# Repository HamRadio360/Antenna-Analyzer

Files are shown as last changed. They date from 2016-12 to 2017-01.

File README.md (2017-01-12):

Ham Radio 360 Logo Workbench Podcast Logo Workbench Logo

# K6BEZ Antenna Analyzer

The K6BEZ antenna analyzer will provide VSWR measurements for any antenna from 1 to 30 MHz.  Frequency and VSWR is shown on the built in LCD display.  Data can optionally be sent over the USB cable to a PC running a program that will plot the VSWR on a graphical window display.
The analyzer can be programmed to scan any sub band and has built in ranges for 160m, 80m, 60m, 40m, 30m, 20m, 17m, 15m, 12m, 10m. 

For more information check out the [project website](http://www.360workbench.com/) and the [Ham Radio 360 forum](http://hamradio360.com/community/main-forum/).

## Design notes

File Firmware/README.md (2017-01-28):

Ham Radio 360 Logo Workbench Podcast Logo Workbench Logo

# Firmware

This directory contains the firmware for the K6BEZ Antenna Analyzer.

Currently the firmware supports revision 6 and 7 PCBs with Arduino Pro Mini compatible microcontrollers and Analog Devices AD9850 synthesizers.

## Standard Firmware

This is the firmware originally developed by K6BEZ and supports the core features of the antenna analyzer. If you are getting started or want reliable and stable software use the standard firmware.

## Advanced Firmware

This firmware contains more features but may require more work to build and install.

# Issues, Bugs, Ideas for improvements

We are tracking all issues and ideas for improvements using the [GitHub issues](https://github.com/HamRadio360/Antenna-Analyzer/issues) tracker.

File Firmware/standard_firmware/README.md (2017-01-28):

Ham Radio 360 Logo Workbench Podcast Logo Workbench Logo

# Standard Firmware

This directory contains the standard firmware for the K6BEZ Antenna Analyzer.

Currently the firmware supports revision 6 and 7 PCBs with Arduino Pro Mini compatible microcontrollers and Analog Devices AD9850 synthesizers.

# Installing

The firmware can be built and installed using the Arduino Integrated Development Environment (IDE).

1. Install the [Arduino IDE Editor & Compiler](https://www.arduino.cc/en/Main/Software)
2. Add the SparkFun Board Manager URLs
  * Go to File / Preferences, and paste this URL into the 'Additional Boards Manager URLs' input field...
  * https://raw.githubusercontent.com/sparkfun/Arduino_Boards/master/IDE_Board_Manager/package_sparkfun_index.json
3. Install the Arduino Pro Micro board definitions file
  * This board file will work for the SparkFun or DealExtreme Arduino Pro Micro board
  * In the Arduino IDE, click Tools / Board / then scroll to the top and click <Board Manager>
  * At the top of the Board Manager enter "sparkfun" and hit return
  * You will see multiple Sparkfun board definition sets
  * Click on the box labeled “SparkFun AVR Boards”
  * Click **Install**
4. Open the firmware project
  * Go to File / Open and select the `aa_firmware.ino` file
5. Select the target board
  * Go to Tools / Board and scroll down to select "SparkFun Pro Micro"
  * Go to Tools / Processor and select "ATmega32u4 (5V, 16 MHz)"
  * Go to Tools / Port and select the correct Serial Port. This varies based on your Operating System and computer hardware.
5. Upload the firmware
  * Go to Sketch / Upload

# Troubleshooting

The Arduino IDE and the USB connection can be inconsistent sometimes. There are many resources online talking about programming the Arduino on every imaginable operating system and with almost any error.

If you have problems the [Ham Radio 360 Forum](http://hamradio360.com/community/build-discussion/) is a good place to ask. Please include what operating system you are on and any error message you've encountered.

# Issues, Bugs, Ideas for improvements

We are tracking all issues and ideas for improvements using the [GitHub issues](https://github.com/HamRadio360/Antenna-Analyzer/issues) tracker.

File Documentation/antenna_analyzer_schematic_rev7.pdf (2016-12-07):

# Antenna Analyzer Rev 7 Schematic

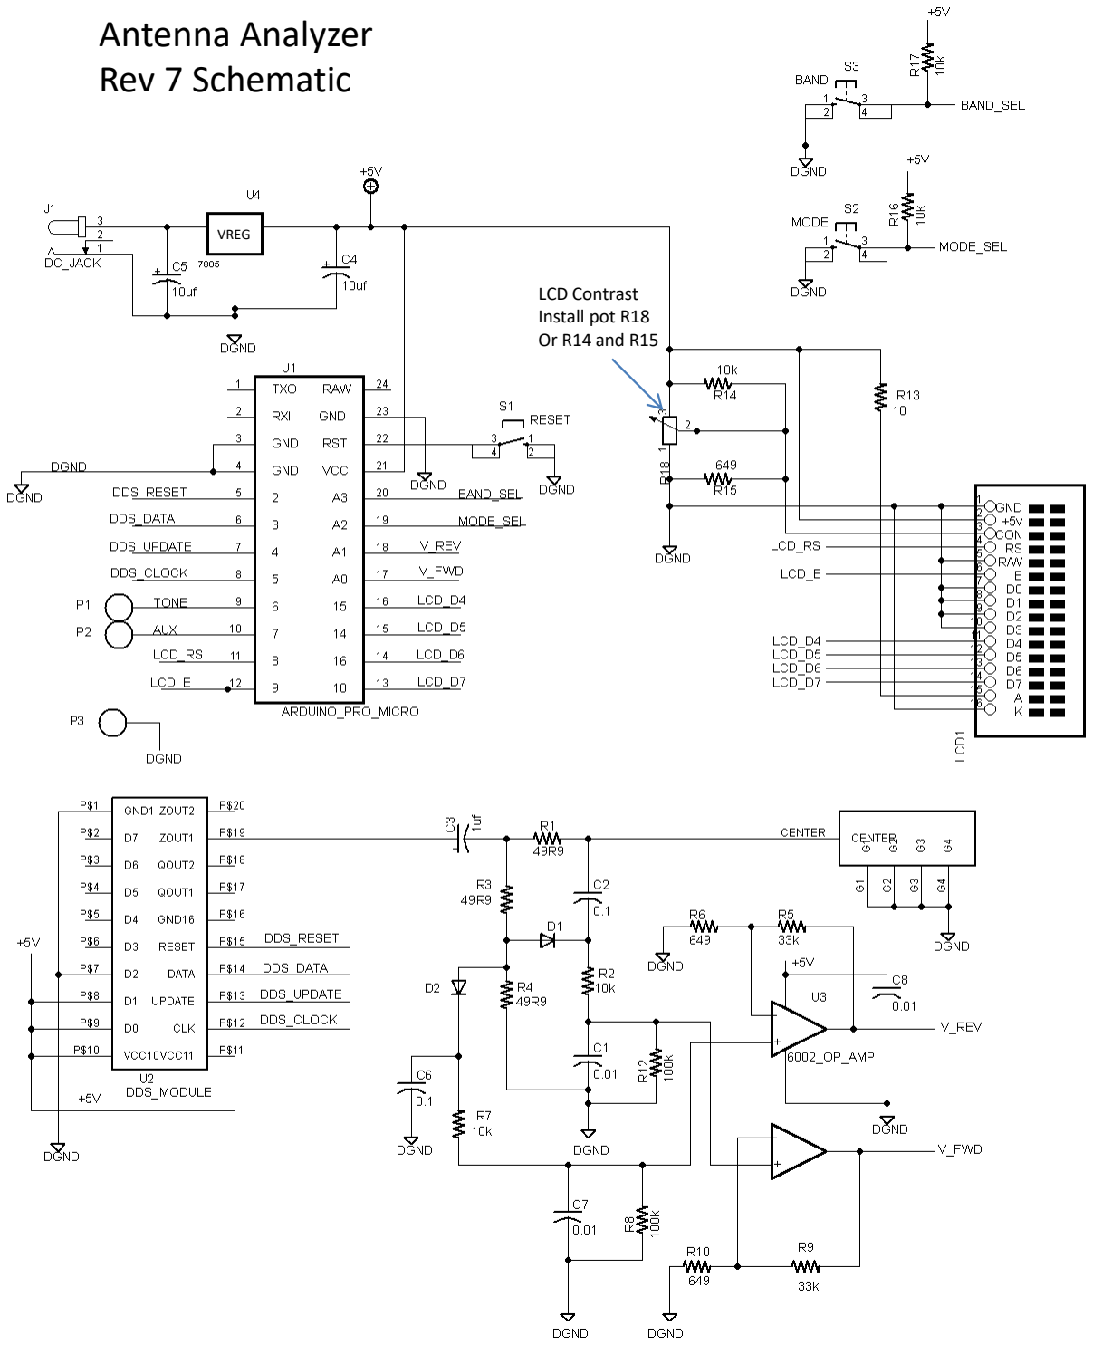
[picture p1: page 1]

VREG

LCD Contrast
Install pot R18
Or R14 and R15

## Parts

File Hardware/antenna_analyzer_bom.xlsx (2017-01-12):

HamRadio 360 Workbench - K6BEZ Antenna Analyzer Bill of Materials
Type | Part | Description | Value | Digikey Part # | Est Price | Web Site
Connector | CON1 | Right angle BNC connector |  | A97569-ND | $3.88
Connector | J1 | DC power jack 2.1mm |  | CP-102AH-ND | $1.18
Capacitor | C1 | 0.1" spaced dipped mono 10% | 0.01 | 399-4260-ND | $0.24
Capacitor | C2 | 0.1" spaced dipped mono 10% | 0.1 | BC1084CT-ND | $0.22
Capacitor | C3 | Electrolytic capacitor 25v | 1uf | 493-10461-1-ND | $0.10
Capacitor | C4 | Electrolytic capacitor 25v | 10uf | P980-ND | $0.23
Capacitor | C5 | Electrolytic capacitor 25v | 10uf | P980-ND | $0.23
Capacitor | C6 | 0.1" spaced dipped mono 10% | 0.1 | BC1084CT-ND | $0.22
Capacitor | C7 | 0.1" spaced dipped mono 10% | 0.01 | 399-4260-ND | $0.24
Capacitor | C8 | 0.1" spaced dipped mono 10% | 0.01 | 399-4260-ND | $0.24
Resistor | R1 | 1/4 Watt 5% | 49.9 | 49.9XBK-ND | $0.10
Resistor | R2 | 1/4 Watt 5% | 10k | 10KQBK-ND | $0.10
Resistor | R3 | 1/4 Watt 5% | 49.9 | 49.9XBK-ND | $0.10
Resistor | R4 | 1/4 Watt 5% | 49.9 | 49.9XBK-ND | $0.10
Resistor | R5 | 1/4 Watt 5% | 649 | 649XBK-ND | $0.10
Resistor | R6 | 1/4 Watt 5% | 33k | 33KQBK-ND | $0.10
Resistor | R7 | 1/4 Watt 5% | 10k | 10KQBK-ND | $0.10
Resistor | R8 | 1/4 Watt 5% | 100k | 100KQBK-ND | $0.10
Resistor | R9 | 1/4 Watt 5% | 649 | 649XBK-ND | $0.10
Resistor | R10 | 1/4 Watt 5% | 33k | 33KQBK-ND | $0.10
Resistor | R12 | 1/4 Watt 5% | 100k | 100KQBK-ND | $0.10
Resistor | R13 | 1/4 Watt 5% | 10 | 10QBK-ND | $0.10
Resistor | R14 | 1/4 Watt 5% | 10k | 10KQBK-ND | $0.10
Resistor | R15 | 1/4 Watt 5% | 649 | 649XBK-ND | $0.10
Resistor | R16 | 1/4 Watt 5% | 10k | 10KQBK-ND | $0.10
Resistor | R17 | 1/4 Watt 5% | 10k | 10KQBK-ND | $0.10
Switch | S1 | Tactile pushbutton switch |  | 450-1650-ND | $0.10
Switch | S2 | Tactile pushbutton switch |  | 450-1650-ND | $0.10
Switch | S3 | Tactile pushbutton switch |  | 450-1650-ND | $0.10
Integrated Circuit | U3 | MCP 6002 Dual OpAmp |  | MCP6002-E/P-ND | $0.36
Integrated Circuit | U4 | 5v DC / DC converter OKI-78SR-5/1.5-W36H-C |  | 811-2692-ND | $4.31
Mechanical | X1 | 10 pin female header |  | S7043-ND | $0.85
Mechanical | X2 | 10 pin female header |  | S7043-ND | $0.85
Mechanical | X3 | 16 pin male header 0.1" pitch |  | S1011EC-16-ND | $0.40
Mechanical | X4 | 4-40 Hex standoff 1/4" long, 3/16" diameter |  | 36-1891-ND | $0.40
Mechanical | X5 | 4-40 Hex standoff 1/4" long, 3/16" diameter |  | 36-1891-ND | $0.40
Mechanical | X6 | 4-40 Hex standoff 1/4" long, 3/16" diameter |  | 36-1891-ND | $0.40
Mechanical | X7 | 4-40 Hex standoff 1/4" long, 3/16" diameter |  | 36-1891-ND | $0.40
Mechanical | X8 | 4-40 Hex standoff 1/4" long, 3/16" diameter |  | 36-1891-ND | $0.40
Mechanical | X9 | 4-40 Hex standoff 1/4" long, 3/16" diameter |  | 36-1891-ND | $0.40
Mechanical | X10 | 4-40 Hex standoff 1/4" long, 3/16" diameter |  | 36-1891-ND | $0.40
Mechanical | X11 | 4-40 Hex standoff 1/4" long, 3/16" diameter |  | 36-1891-ND | $0.40
Mechanical | X12 | 4-40 1/4" pan head philips screw |  | 36-9900-ND | $0.10
Mechanical | X13 | 4-40 1/4" pan head philips screw |  | 36-9900-ND | $0.10
Mechanical | X14 | 4-40 1/4" pan head philips screw |  | 36-9900-ND | $0.10
Mechanical | X15 | 4-40 1/4" pan head philips screw |  | 36-9900-ND | $0.10
Mechanical | X16 | 4-40 hex nut |  | 36-4694-ND | $0.08
Mechanical | X17 | 4-40 hex nut |  | 36-4694-ND | $0.08
Mechanical | X18 | 4-40 hex nut |  | 36-4694-ND | $0.08
Mechanical | X19 | 4-40 hex nut |  | 36-4694-ND | $0.08
Mechanical | X20 | 4-40 1/2" pan head philips screw |  | 36-9902-ND | $0.12
Mechanical | X21 | 4-40 1/2" pan head philips screw |  | 36-9902-ND | $0.12
Mechanical | X22 | 4-40 1/2" pan head philips screw |  | 36-9902-ND | $0.12
Mechanical | X23 | 4-40 1/2" pan head philips screw |  | 36-9902-ND | $0.12
Mechanical | X24 | 8 pin DIP socket |  | AE9986-ND | $0.18
 |  |  |  |  | $20.03
Components from Other Internet Sources
Item | Part | Description | Price | Web Site
Integrated Circuit | U1 | Arduino Pro Micro | 5.71 | http://www.dx.com/p/pro-micro-atmega-32u4-5v-16mhz-development-board-module-for-arduino-deep-blue-320958
Integrated Circuit | U2 | AD9850 DDS Module | 12.1 | http://www.ebay.com/itm/AD9850-DDS-Signal-Generator-Module-0-40MHz-2-Sine-Wave-And-2-Square-Wave-Output-/170910337597
LCD | LCD1 | 2x16 LCD Display | $3.41 | http://www.ebay.com/itm/1602-162-16x2-Character-LCD-Display-Module-HD44780-Controller-Yellow-Blacklight-/400436751565
Components from PackTenna
Item | Part | Description | Price | Web Site
Antenna Analyzer Parts Kit includes… |  |  | $16.80
 | PCB | Printed circuit board
 | D1 | AA143 Germanium diode
 | D2 | AA143 Germanium diode

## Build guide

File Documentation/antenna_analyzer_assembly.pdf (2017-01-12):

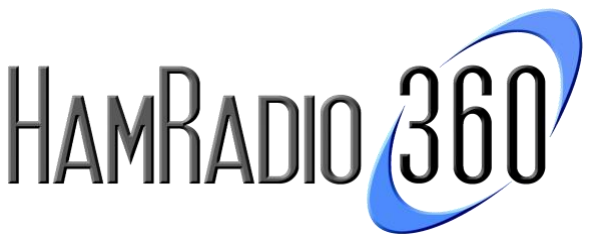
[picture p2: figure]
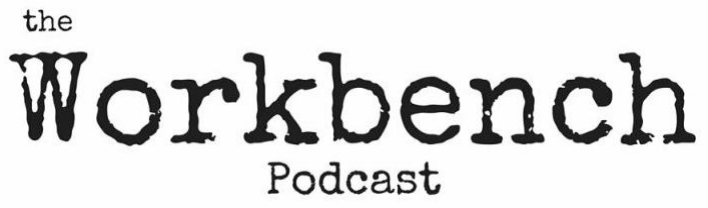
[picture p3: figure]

# Antenna Analyzer Assembly Guide

## Rev 1.1

## Introduction

The Workbench antenna analyzer project was designed by Beric Dunn, K6BEZ. This assembly guide explains how to build the antenna analyzer. The theory of operation is documented elsewhere. For all the latest documents go to www.360workbench.com

## General Assembly Instructions

We recommend assembling the antenna analyzer in the following order.

Install all low profile components first.
☐ Install all resistors
If you have a version 6 board read the page “Alert ! Rev 6 Board Changes“ page in this document to see the four silkscreen changes to the board.
If you have a version 7 or later board, install the resistors as marked on the board.
☐ Install all capacitors
☐ Install the two glass germanium diodes
☐ Install the 8 pin IC socket
☐ Install the 3 tactile switches
Install connectors
☐ Install the two 10 pin female header sockets for the DDS module
☐ Install the one 16 pin male header connector for the LCD display
☐ Install the two 12 pin male header connectors for the Arduino module ☐ Install the DC coaxial power jack
☐ Install the BNC coax jack
Install the voltage regulator
☐ Install the voltage regulator module.
At this point, check to make sure the DC voltages are correct. See the DC Test Point page. Install standoffs
☐ Install the 4 ¼” hex standoffs to the LCD module using 4 of the ½” 4-40 screws
☐ Install the 4 ¼” hex standoffs to the main PCB in the corners using 4-40 screws
Mount the LCD
☐ Place the ½” screws that are part of the LCD module through the holes on the PCB and attach with 4-40 nuts on the bottom of the board
Install Arduino
☐ Place the Arduino module on the male headers and solder. Make sure the micro USB jack is pointing to the edge of the board.
Install the DDS module
☐ Plug the DDS module on to the main PCB.

## Antenna Analyzer Rev 7 Schematic

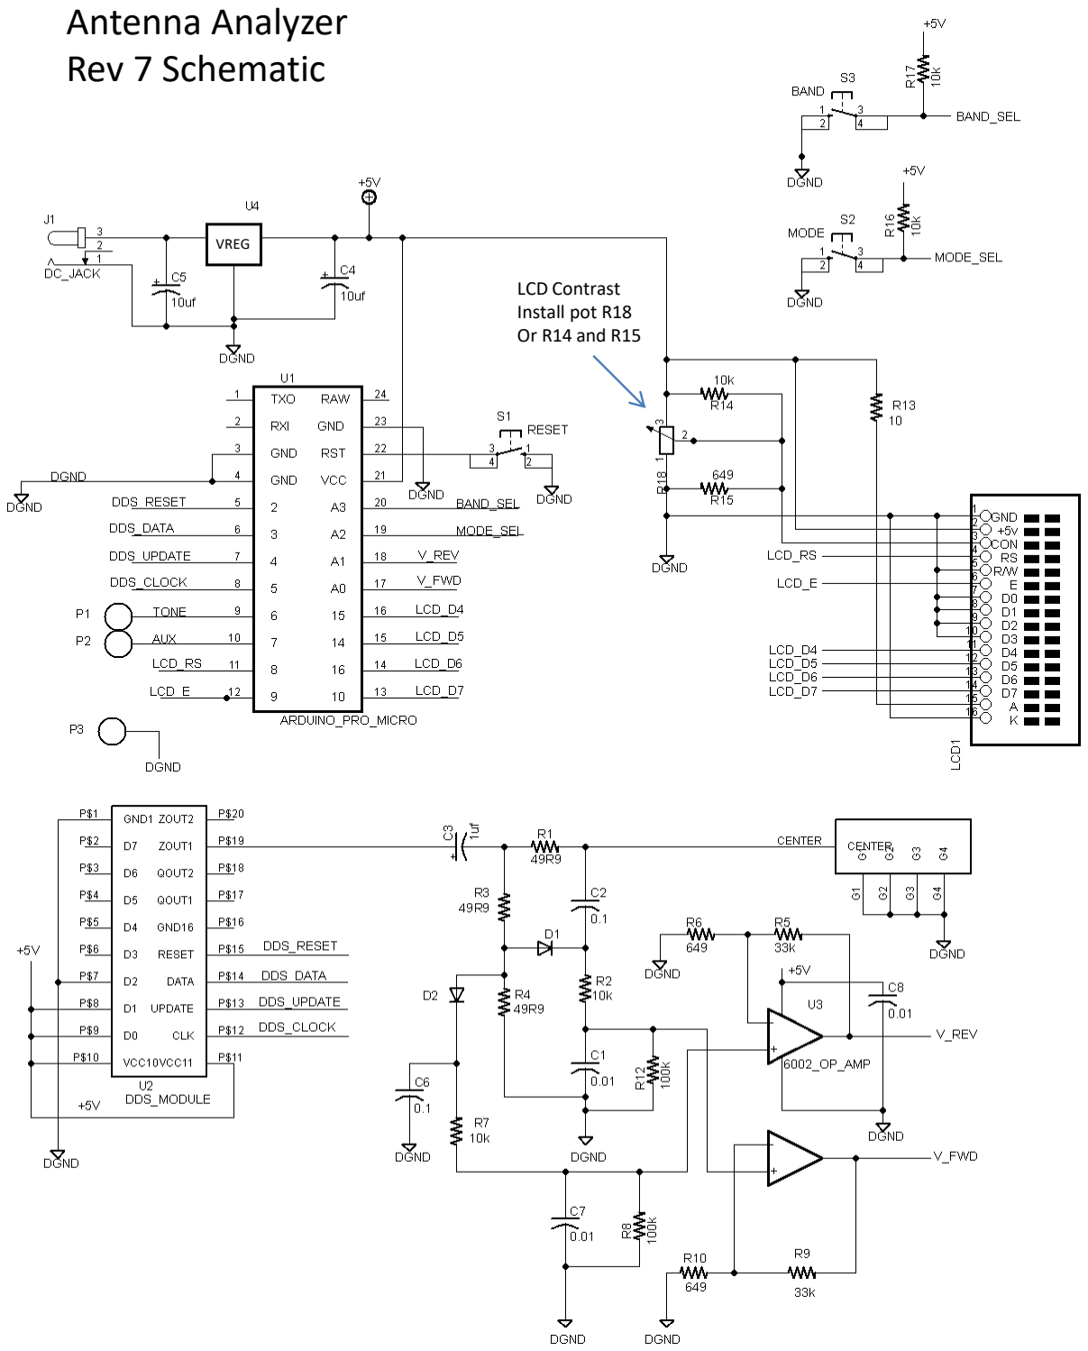
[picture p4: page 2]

VREG

LCD Contrast
Install pot R18
Or R14 and R15

# Bill of Materials

Type | Part | Description | Value | Digikey Part #
Connector | CON1 | Right angle BNC connector | A97569-ND
Connector | J1 | DC power jack 2.1mm | CP-102AH-ND
Capacitor | C1 | 0.1" spaced dipped mono 10% | 0.01 | 399-4260-ND
Capacitor | C2 | 0.1" spaced dipped mono 10% | 0.1 | BC1084CT-ND
Capacitor | C3 | Electrolytic capacitor 25v | 1uf | 493-10461-1-ND
Capacitor | C4 | Electrolytic capacitor 25v | 10uf | P980-ND
Capacitor | C5 | Electrolytic capacitor 25v | 10uf | P980-ND
Capacitor | C6 | 0.1" spaced dipped mono 10% | 0.1 | BC1084CT-ND
Capacitor | C7 | 0.1" spaced dipped mono 10% | 0.01 | 399-4260-ND
Capacitor | C8 | 0.1" spaced dipped mono 10% | 0.01 | 399-4260-ND
Resistor | R1 | 1/4 Watt 5% | 49.9 | 49.9XBK-ND
Resistor | R2 | 1/4 Watt 5% | 10k | 10KQBK-ND
Resistor | R3 | 1/4 Watt 5% | 49.9 | 49.9XBK-ND
Resistor | R4 | 1/4 Watt 5% | 49.9 | 49.9XBK-ND
Resistor | R5 | 1/4 Watt 5% | 649 | 649XBK-ND
Resistor | R6 | 1/4 Watt 5% | 33k | 33KQBK-ND
Resistor | R7 | 1/4 Watt 5% | 10k | 10KQBK-ND
Resistor | R8 | 1/4 Watt 5% | 100k | 100KQBK-ND
Resistor | R9 | 1/4 Watt 5% | 649 | 649XBK-ND
Resistor | R10 | 1/4 Watt 5% | 33k | 33KQBK-ND
Resistor | R12 | 1/4 Watt 5% | 100k | 100KQBK-ND
Resistor | R13 | 1/4 Watt 5% | 10 | 10QBK-ND
Resistor | R14 | 1/4 Watt 5% | 10k | 10KQBK-ND
Resistor | R15 | 1/4 Watt 5% | 649 | 649XBK-ND
Resistor | R16 | 1/4 Watt 5% | 10k | 10KQBK-ND
Resistor | R17 | 1/4 Watt 5% | 10k | 10KQBK-ND
Switch | S1 | Tactile pushbutton switch | 450-1650-ND
Switch | S2 | Tactile pushbutton switch | 450-1650-ND
Switch | S3 | Tactile pushbutton switch | 450-1650-ND
Integrated Circuit | U3 | MCP 6002 Dual OpAmp | MCP6002-E/P-ND
Integrated Circuit | U4 | 5v DC / DC converter OKI-78SR-5/1.5-W36H-C | 811-2692-ND

# Bill of Materials

Mechanical | X1 | 10 pin female header | S7043-ND
Mechanical | X2 | 10 pin female header | S7043-ND
Mechanical | X3 | 16 pin male header 0.1" pitch | S1011EC-16-ND
Mechanical | X4 | 4-40 Hex standoff 1/4" long, 3/16" diameter | 36-1891-ND
Mechanical | X5 | 4-40 Hex standoff 1/4" long, 3/16" diameter | 36-1891-ND
Mechanical | X6 | 4-40 Hex standoff 1/4" long, 3/16" diameter | 36-1891-ND
Mechanical | X7 | 4-40 Hex standoff 1/4" long, 3/16" diameter | 36-1891-ND
Mechanical | X8 | 4-40 Hex standoff 1/4" long, 3/16" diameter | 36-1891-ND
Mechanical | X9 | 4-40 Hex standoff 1/4" long, 3/16" diameter | 36-1891-ND
Mechanical | X10 | 4-40 Hex standoff 1/4" long, 3/16" diameter | 36-1891-ND
Mechanical | X11 | 4-40 Hex standoff 1/4" long, 3/16" diameter | 36-1891-ND
Mechanical | X12 | 4-40 1/4" pan head philips screw | 36-9900-ND
Mechanical | X13 | 4-40 1/4" pan head philips screw | 36-9900-ND
Mechanical | X14 | 4-40 1/4" pan head philips screw | 36-9900-ND
Mechanical | X15 | 4-40 1/4" pan head philips screw | 36-9900-ND
Mechanical | X16 | 4-40 hex nut | 36-4694-ND
Mechanical | X17 | 4-40 hex nut | 36-4694-ND
Mechanical | X18 | 4-40 hex nut | 36-4694-ND
Mechanical | X19 | 4-40 hex nut | 36-4694-ND
Mechanical | X20 | 4-40 1/2" pan head philips screw | 36-9902-ND
Mechanical | X21 | 4-40 1/2" pan head philips screw | 36-9902-ND
Mechanical | X22 | 4-40 1/2" pan head philips screw | 36-9902-ND
Mechanical | X23 | 4-40 1/2" pan head philips screw | 36-9902-ND
Mechanical | X24 | 8 pin DIP socket | AE9986-ND

Components from Other Internet Sources
Item | Part | Description
Integrated Circuit | U1 | Arduino Pro Micro
Integrated Circuit | U2 | AD9850 DDS Module
LCD | LCD1 | 2x16 LCD Display

Components from PackTenna
Item | Part | Description

Antenna Analyzer Parts Kit includes…
PCB | Printed circuit board
D1 | AA143 Germanium diode
D2 | AA143 Germanium diode

Arduino Pro Micro 5v Example http://www.dx.com/p/pro-micro-atmega-32u4-5v-16mhz-development-boardmodule-for-arduino-deep-blue-320958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
DDS Module example on Ebay http://www.ebay.com/itm/AD9850-DDS-Signal-Generator-Module-0-40MHz-2-Sine-Wave-And-2-Square-Wave-Output-/170910337597

LCD example on Ebay
http://www.ebay.com/itm/1602-162-16x2-Character-LCD-Display-Module-HD44780-Controller-Yellow-Blacklight-/400436751565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 iMAAOSwZVlXkHXi

## The Workbench – Antenna Analyzer Parts Placement Diagram

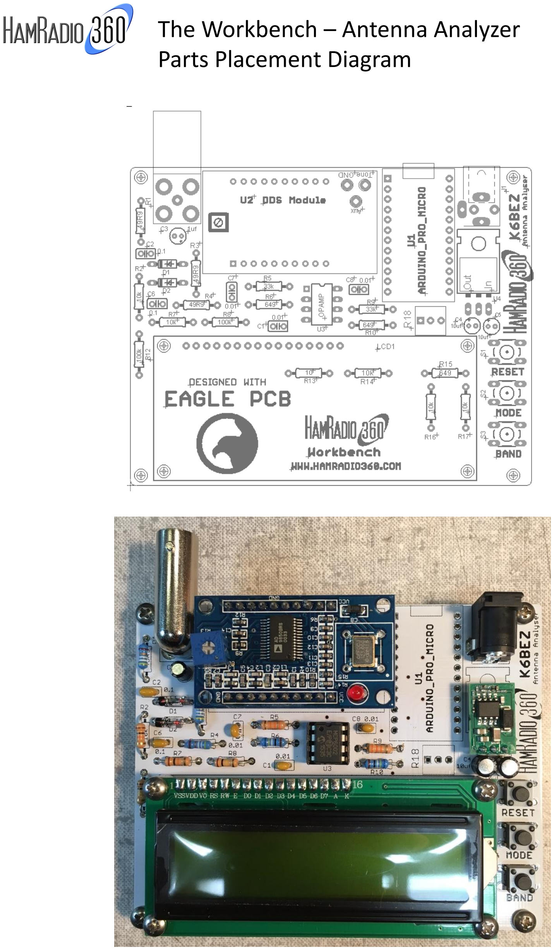
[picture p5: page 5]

Install all low profile components first.
☐ Install all resistors
☐ Install all capacitors
☐ Install the two glass germanium diodes ☐ Install the 8 pin IC socket
☐ Install the 3 tactile switches

Install connectors
☐ Install the two 10 pin female header sockets for the DDS module
☐ Install the one 16 pin male header connector for the LCD display
☐ Install the two 12 pin male header connectors for the Arduino module ☐ Install the DC coaxial power jack
☐ Install the BNC coax jack

Install the voltage regulator
☐ Install the voltage regulator module.

If you have a rev 6 board,

## look at the builder’s alert on

the next page.

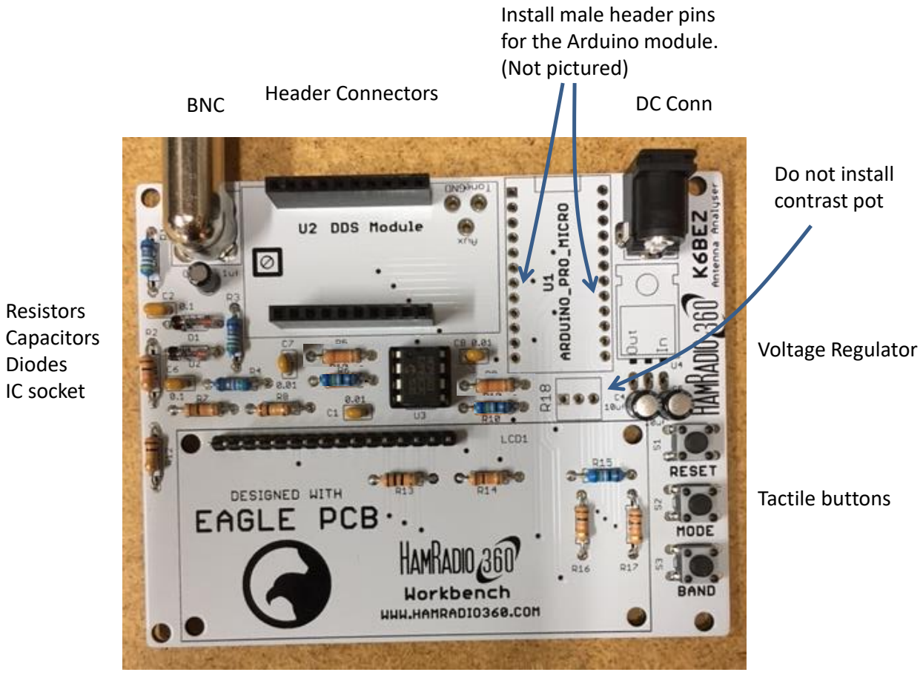
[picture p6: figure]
BNC; DC Conn; Voltage Regulator; Resistors Capacitors Diodes IC socket; Tactile buttons; Do not install contrast pot; Header Connectors; Install male header pins for the Arduino module. (Not pictured)

There is a mistake on the rev 6 board silkscreen. Look on the back of the board for the text like “Rev 6” on the back. If it says “Rev 6” there is a mistake on the text for four of the resistors. The parts list has all the right components, they just need to be put in different places. All boards rev 7 and beyond are labeled

correctly on the board.

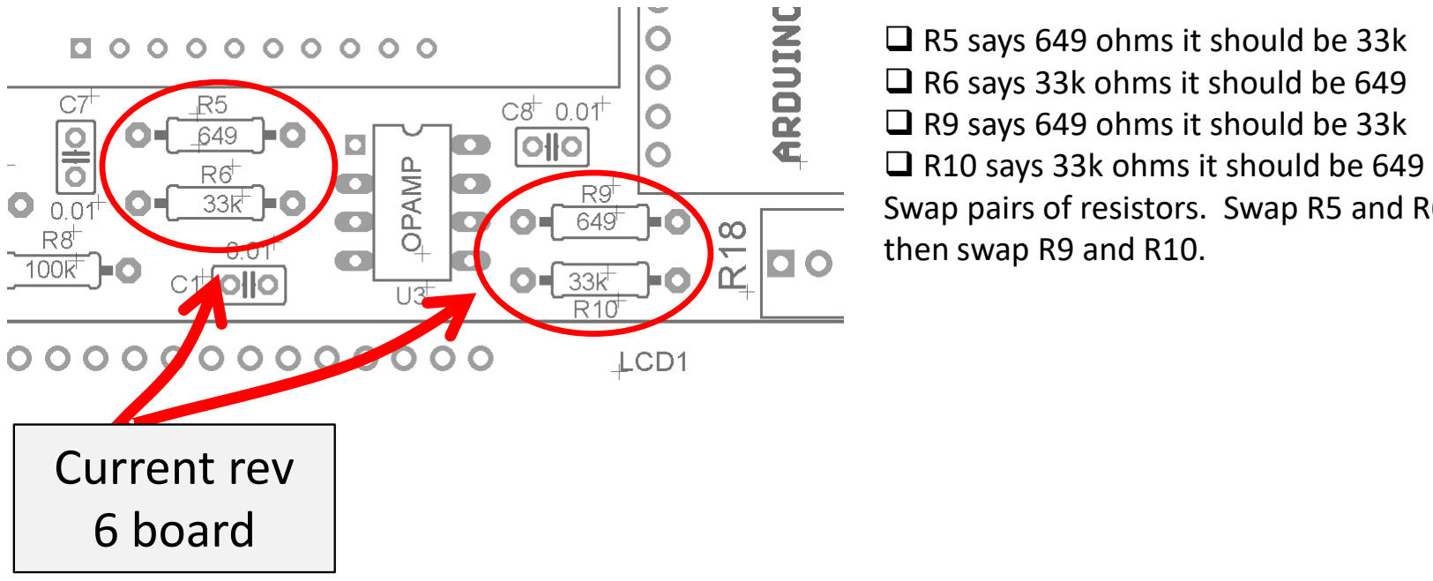
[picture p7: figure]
☐ R5 says 649 ohms it should be 33k ☐ R6 says 33k ohms it should be 649 ☐ R9 says 649 ohms it should be 33k ☐ R10 says 33k ohms it should be 649; then swap R9 and R10.; Current rev 6 board

Swap pairs of resistors. Swap R5 and R6 and

# Alert ! Rev 6 Board Changes

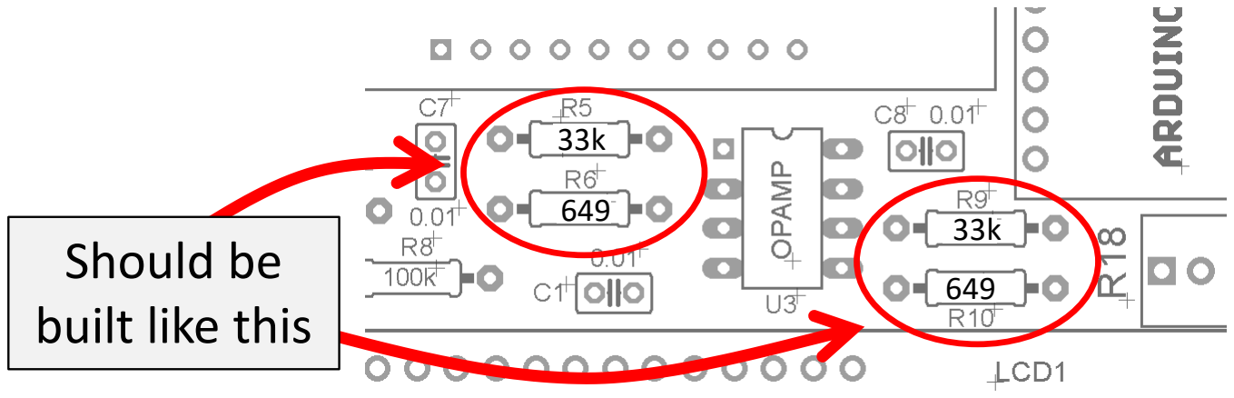
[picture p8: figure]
Should be built like this

# Voltage Regulator

The antenna analyzer’s voltage regulator is a three terminal switching power supply module. We recommend the OKI-78SR-5/1.5-W36H-C made by MuRata. When you look at the solder pads of the component outline, it is similar to a 7805 linear regulator *except* that the pins are backwards.

The board is designed to have the switching regulator module mounted upside down to allow the pins to pass through the main PCB. The big advantage of the switching regulator is that you can run the device as high as 14 VDC and not generate excessive heat.

You can use a good old linear regulator (7805) if you mount it upside down. Be aware that we only advise doing this if you are running on a low input voltage round 7 volts.

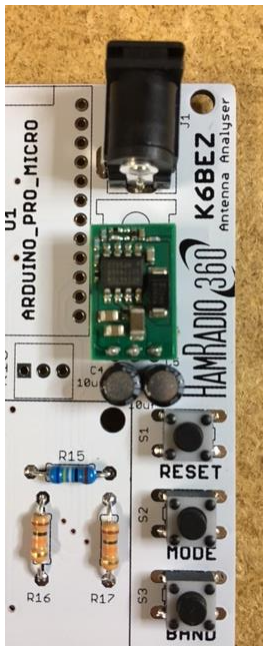
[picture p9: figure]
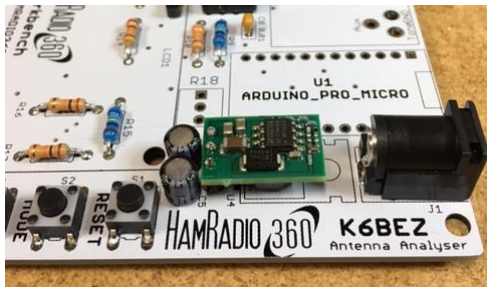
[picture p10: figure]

# Assemble LCD Module

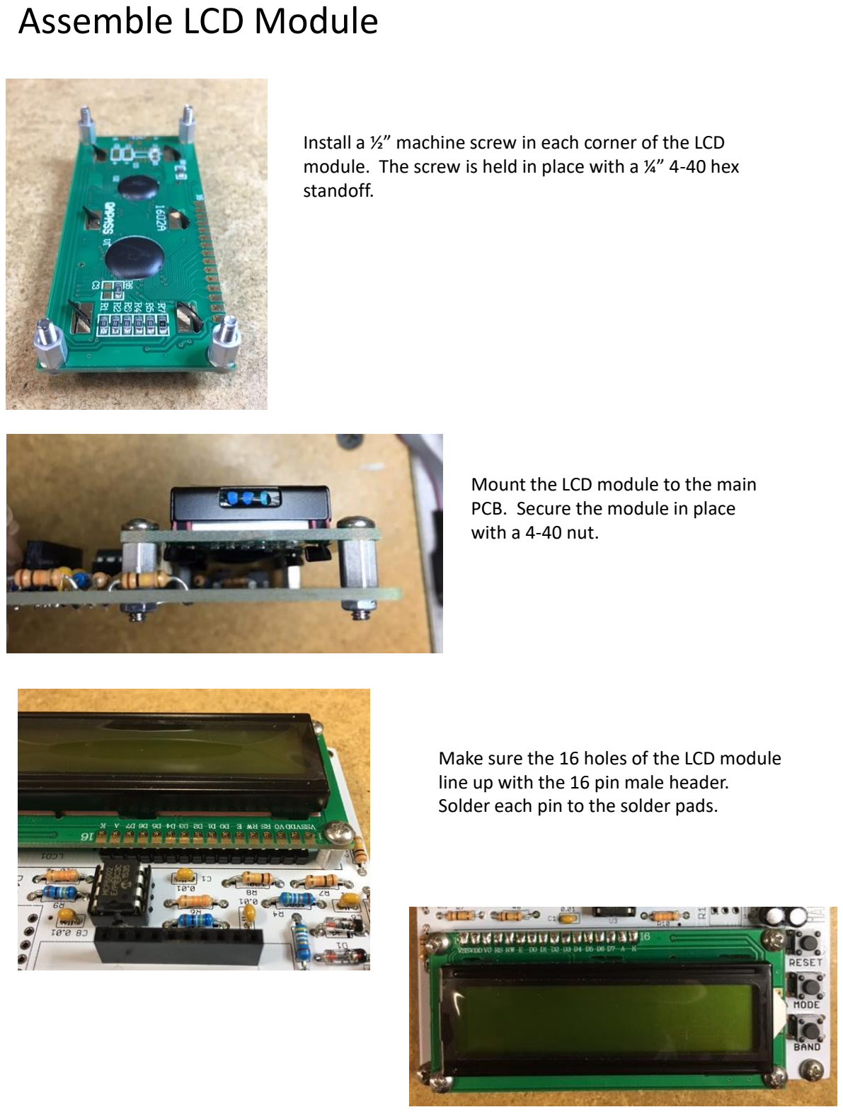
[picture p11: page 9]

Install a ½” machine screw in each corner of the LCD module. The screw is held in place with a ¼” 4-40 hex standoff.

Mount the LCD module to the main PCB. Secure the module in place with a 4-40 nut.

Make sure the 16 holes of the LCD module line up with the 16 pin male header. Solder each pin to the solder pads.

# Arduino Module

The brains of the board is the Arduino processor module. This board is called an Arduino Pro Micro 5v version. This tells you the shape, configuration and voltage of the board.

When installing the Arduino module, first solder the two 12 pin male headers that came with the Arduino. Solder them to the top of the board like you would normally do. This means the black plastic part that holds all the pins together is touching the surface of the antenna analyzer board.

After the headers are soldered in place, drop the Arduino module onto the pins.
Make sure the micro USB socket is pointing to the edge of the board.
Now that you have confirmed the board is placed in the right direction, solder the 24 pins of the header on the top of the Arduino board module.

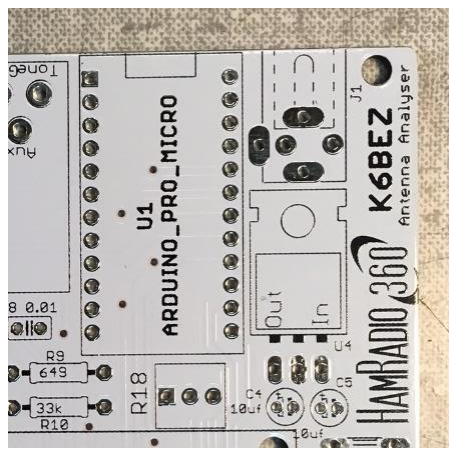
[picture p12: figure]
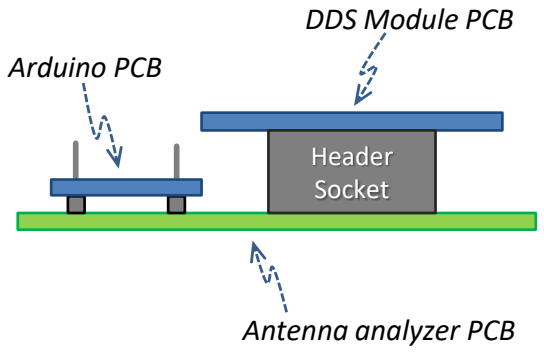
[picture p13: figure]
Header Socket; Antenna analyzer PCB; DDS Module PCB; Arduino PCB

The DDS synthesis module will be significantly higher than the Arduino board.

Rear board edge | Rear board edge

View from the rear

# Assembled Unit

Arduino module not shown in this picture.

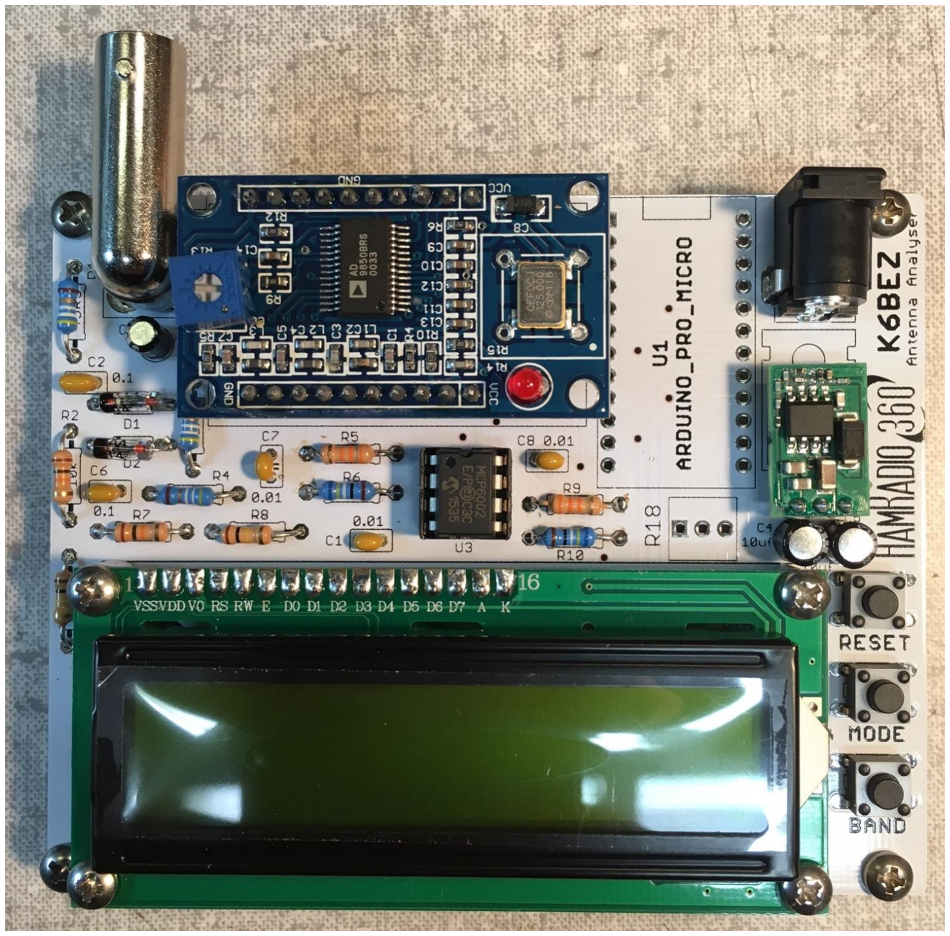
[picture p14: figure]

# DC Test Points

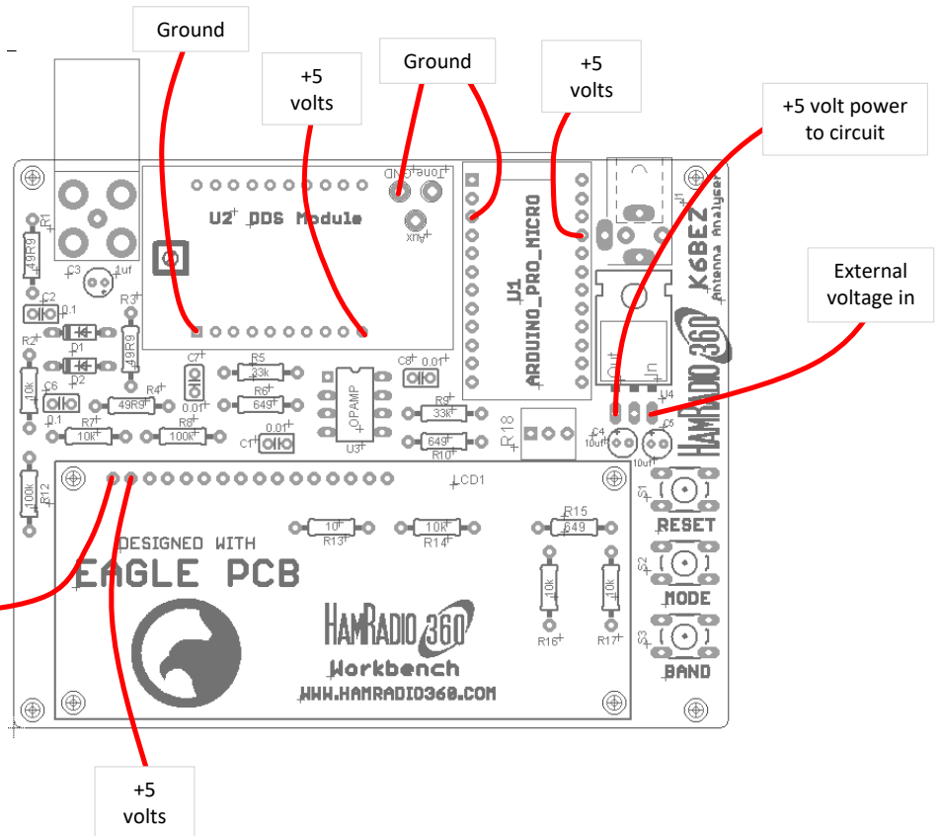
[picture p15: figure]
External voltage in; +5 volt power to circuit; +5 volts; Ground; volts

Ground

Before you install the Arduino, DDS module and LCD, you should power up the board to make sure power is properly going to each of the key test points.

# RF Test Points

RF signal out

These are the critical signal test points if you want to measure the RF Signal path.

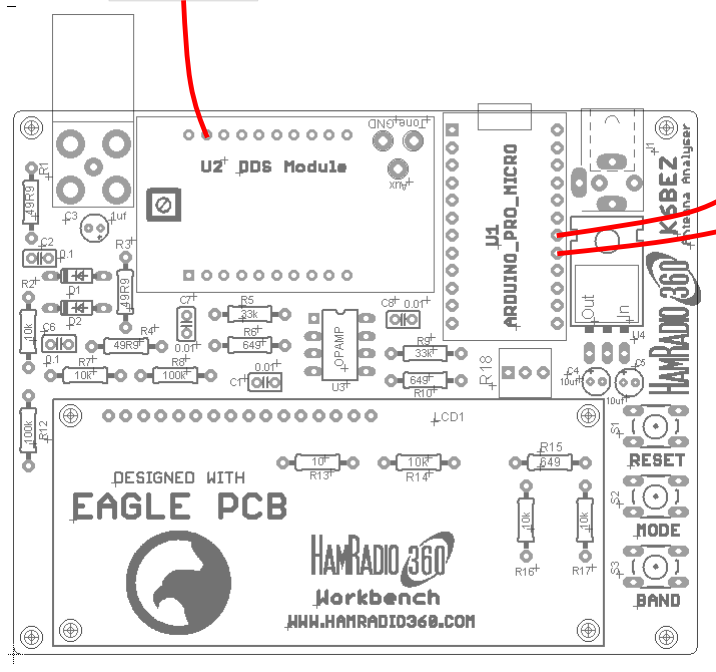
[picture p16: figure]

Forward voltage

Reflected voltage

Analog to digital (ADC)
converter inputs

# Digital Test Points

These are digital connections from the Arduino to the DDS module and the LCD. Reset Data Strobe Clock

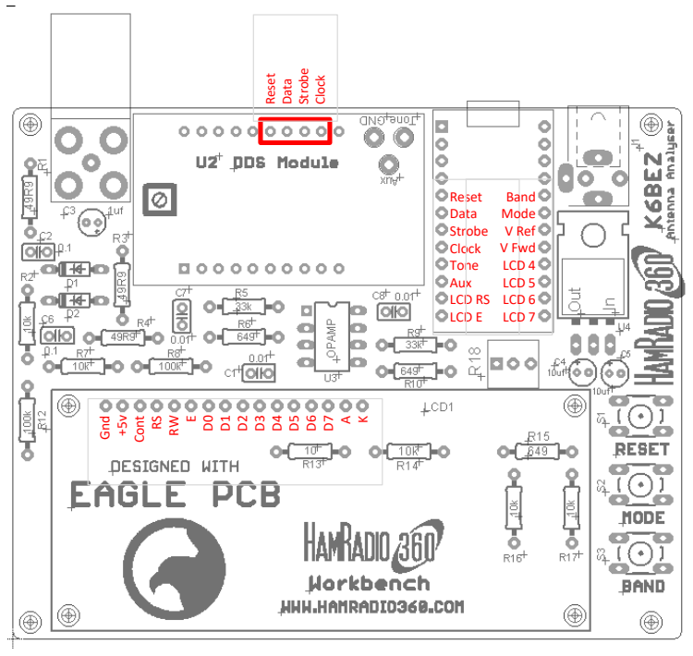
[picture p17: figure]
Reset Data Strobe Clock Tone Aux LCD RS LCD E; Band Mode V Ref V Fwd LCD 4 LCD 5 LCD 6 LCD 7; Gnd; Cont

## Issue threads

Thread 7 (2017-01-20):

SetDDSFreq calculation ambiguous

JohnDSutter, 2017-01-20:
On Arduino 1.6.5 it consistently gets the wrong answer giving me a nice
~1Hz signal.  The following is a bit more explicit:

void SetDDSFreq(long Freq_Hz) {
	// Calculate the DDS word - from AD9850 Datasheet
	uint32_t f = (uint32_t) (((uint64_t)Freq_Hz * 4294967295ULL)/125000000ULL);

dkozel, 2017-01-20:
Hi @JohnDSutter. Thanks for the bug report. I should be able to check this this weekend.

etchorner, 2017-02-03:
This may be IDE version dependent. On 1.8.1, this bug does not exist. A user on the HR360 forum points out that this bug is likely the result of variable overflow, in the const arithmetic of SetDDSFreq, where the 4294967295 const is already at the limit of a 32 bit variable.

An alternative to that of @JohnDSutter  would be to replace the const division term (4294967295/125000000) with the simple integer 34. Not all version of the IDE may support uint64_t or long long casts for const arithmetic.

JohnDSutter, 2017-02-03:
There is a difference between

  (Freq_Hz * 4294967295)/125000000

and

  Freq_Hz * (4294967295/125000000) => Freq_Hz * 34

when using integers

Band

Center Frequency

(Freq_Hz * 4294967295)/125000000

Freq_Hz * (4294967295/125000000)

Actual Frequency

Error (kHz)

% from Center

160

1900000

65283503

64600000

1880107.448

19.89

20%

80

3750000

128849019

127500000

3710738.384

39.26

16%

40

7150000

245672129

243100000

7075141.186

74.86

50%

30

10125000

347892351

344250000

10018993.64

106.01

141%

20

14175000

487049291

481950000

14026591.09

148.41

85%

10

28850000

991278452

980900000

28547947.3

302.05

86%

6

52000000

1786706395

1768000000

51455572.26

544.43

27%

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

etchorner, 2017-02-03:
@JohnDSutter

Agreed. I think your comment and my edit to my earlier comment crossed in ether. I was having a related discussion on the HR360 forum with a fellow who pointed out the error in my integer multiplier suggestion. My (amended) suggestion is to use 34.35973836 as the tuning word multiplier. Conceptually, the 64 bit cast method you propose may likely work as well, but I'm running 1.8.1 not 1.6.5 so I cannot test it here.

r/
Chris

JohnDSutter, 2017-02-03:
If there's room for a floating point library that's just as good.

The difference is negligible.

Thanks,

- John

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

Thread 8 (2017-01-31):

Remove delay() calls

etchorner, 2017-01-31:
I'd like to suggest that the extensive use of delay() calls in the code be reduced/removed. The AD9850 is a full DDS, not a clock generator, so it does not suffer from the need to account for PLL settling time on the order of several milliseconds per change of frequency.  Similarly, the delay() calls for bit-banging the serial lines to the DDS chip do not seem necessary either, based on the chip specs.

Looking at other folks research, the AD9850 settles on a new frequency somewhere around 43 ns or slightly higher, and communication time seems to be on the order of <30ns. If there is concern regarding the acquisition time through the OpAmps and the Arduino's ADC, on the order of about 1 µsec, then perhaps a delay(1) call before the analogRead() calls is suitable. Empirically, I've removed all delay() calls from my local code and the output data remains coherent and in line with the delay()'d code outputs, it just runs a scan in less than 1 second as opposed to 12 seconds.

dkozel, 2017-01-31:
Hi @etchorner.

Speeding up the acquisition time would be a great improvement. Can you make a pull request removing the delays?

etchorner, 2017-01-31:
I'll see what I can do...I've only ever used Github for reposing my personal code, so I've never done a pull or proposed changes. I have a few other ideas, but I'll deal with this one first.

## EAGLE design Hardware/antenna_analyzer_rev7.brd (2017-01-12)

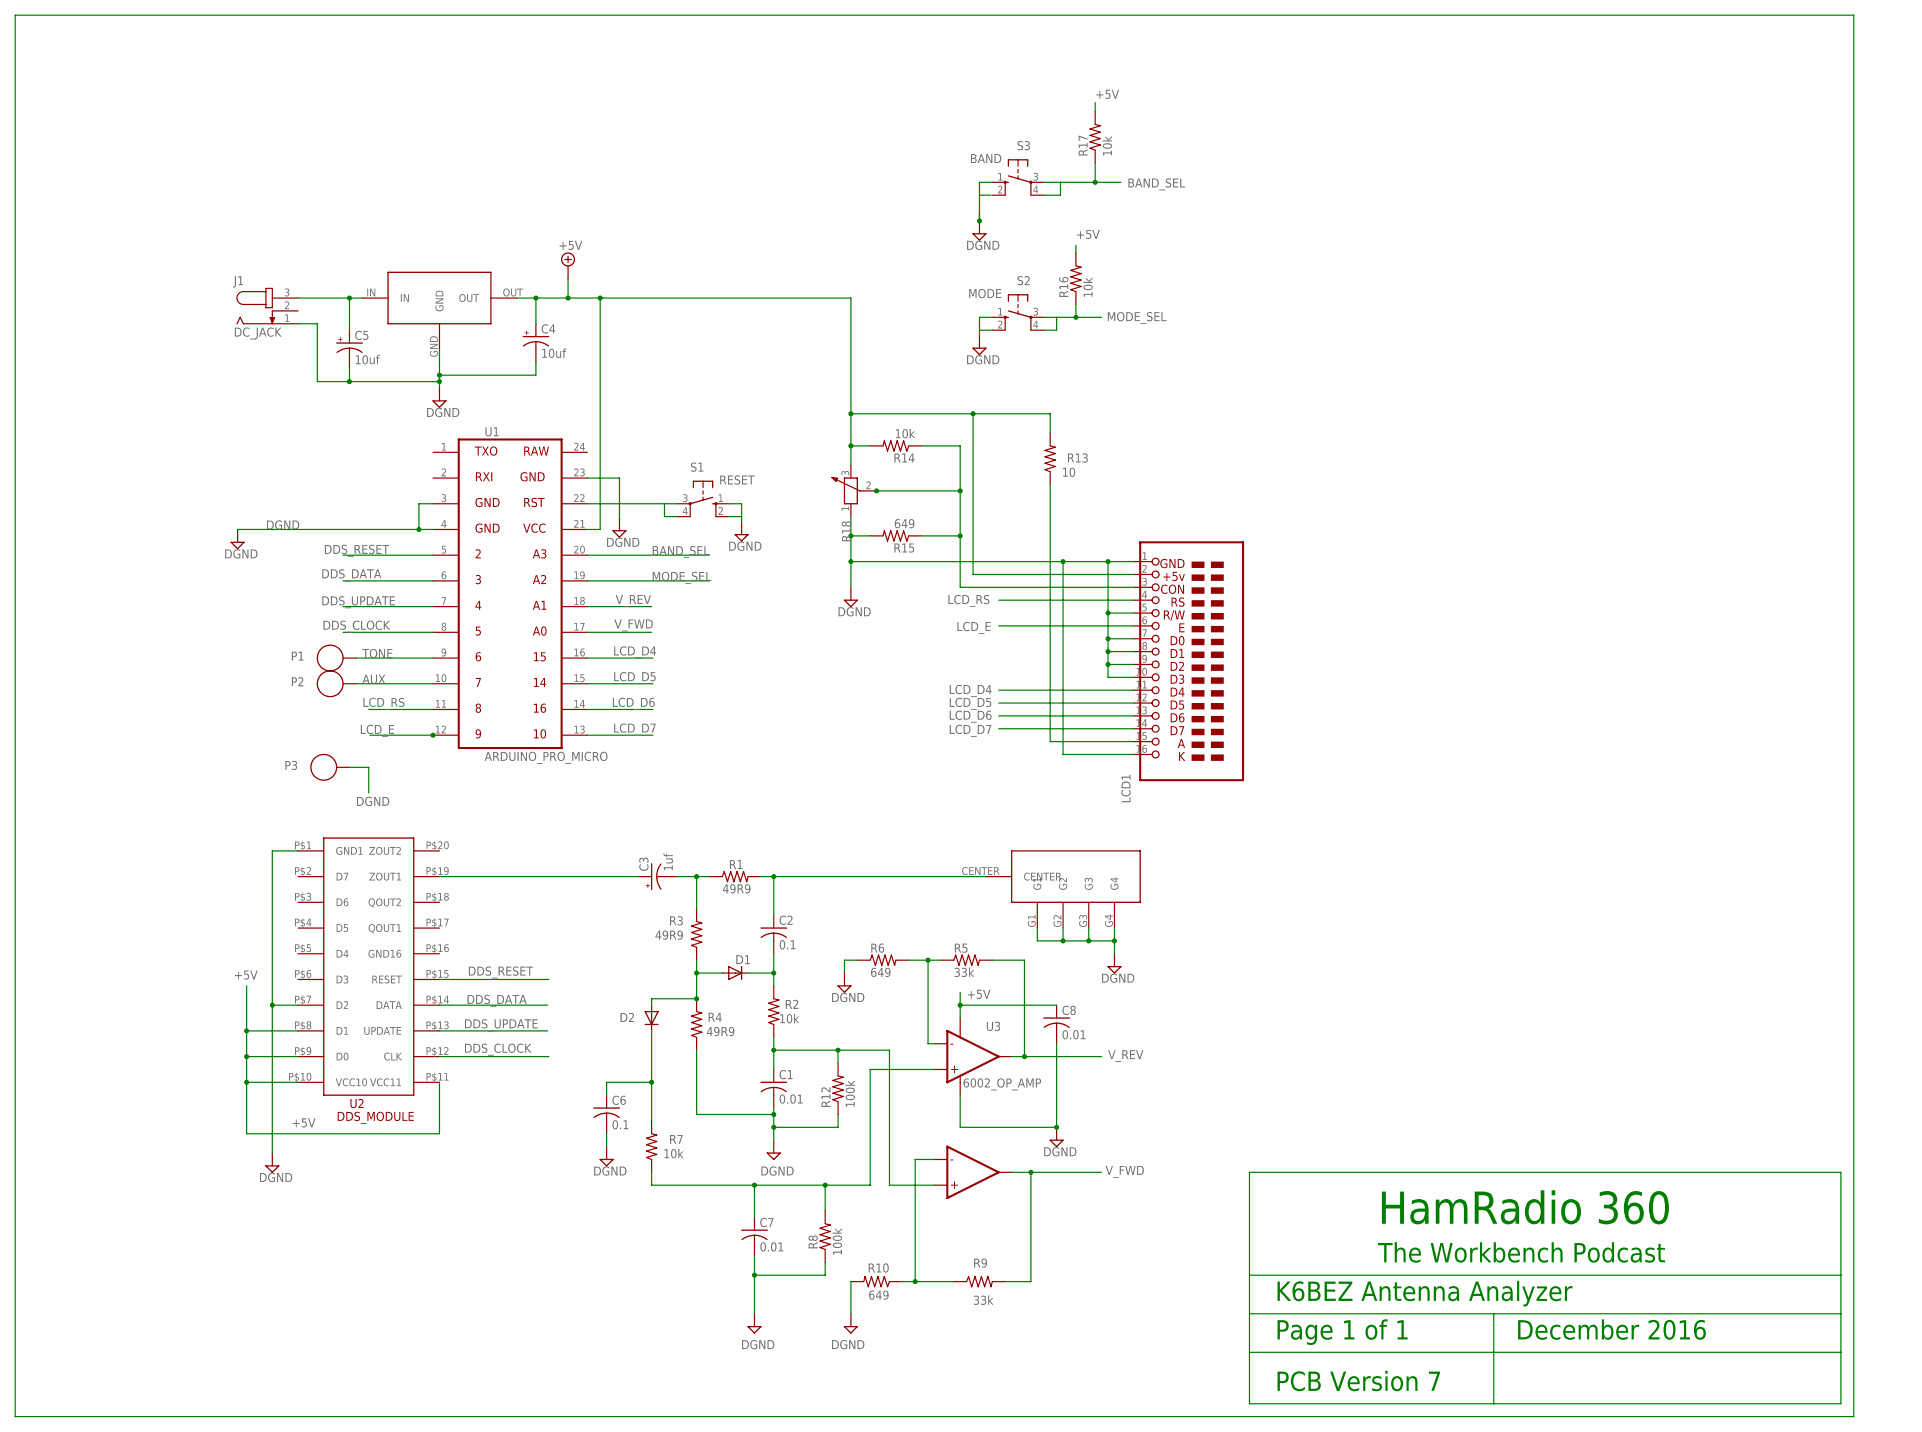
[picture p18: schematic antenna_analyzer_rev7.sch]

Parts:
C1, C7, C8: 0.01; C025-025X050
C2, C6: 0.1; C025-025X050
C3: 1uf; E1,8-4
C4, C5: 10uf; E1,8-4
CON1: BNC-SMALL
D1, D2: AA143; DO35-7
J1: DC_JACK; DC_COAXIAL_JACK
LCD1: LCD_2_16; LCD_2X16
P1, P2, P3: SOLDER_PAD_35_HOLE
R1, R3, R4: 49R9; 0207/10
R2, R7, R14, R16, R17: 10k; 0207/10
R5, R9: 33k; 0207/10
R6, R10, R15: 649; 0207/10
R8, R12: 100k; 0207/10
R13: 10; 0207/10
R18: R-POTENTIOMETER-3362U; 3362U
S1: RESET; B3F-10XX
S2: MODE; B3F-10XX
S3: BAND; B3F-10XX
U1: ARDUINO_PRO_MICRO
U2: AD9850_MOD; DDS_DIL
U3: 6002_OP_AMP; OP_AMP_8_PIN
U5: SWITCHING_REGULATOR

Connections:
+5V: C4.+, C8.1, LCD1.2, R13.2, R14.2, R16.2, R17.2, R18.3 (2), U1.21, U2.P$8 (D1), U2.P$9 (D0), U2.P$10 (VCC10), U2.P$11 (VCC11), U3.8 (VCC+), U5.OUT
AUX: P2.1, U1.10
BAND_SEL: R17.1, S3.3, S3.4 (P1), U1.20
DDS_CLOCK: U1.8, U2.P$12 (CLK)
DDS_DATA: U1.6, U2.P$14 (DATA)
DDS_RESET: U1.5, U2.P$15 (RESET)
DDS_UPDATE: U1.7, U2.P$13 (UPDATE)
DGND: C1.2, C4.-, C5.-, C6.2, C7.2, C8.2, CON1.G1, CON1.G2, CON1.G3, CON1.G4, J1.1, LCD1.1, LCD1.5, LCD1.7, LCD1.8, LCD1.9, LCD1.10, LCD1.16, P3.1, R4.1, R6.1, R8.1, R10.2, R12.1, R15.2, R18.1, S1.1 (S), S1.2 (S1), S2.1 (S), S2.2 (S1), S3.1 (S), U1.3, U1.4, U1.23, U2.P$1 (GND1), U2.P$7 (D2), U3.4 (VCC-), U5.GND
LCD_D4: LCD1.11, U1.16
LCD_D5: LCD1.12, U1.15
LCD_D6: LCD1.13, U1.14
LCD_D7: LCD1.14, U1.13
LCD_E: LCD1.6, U1.12
LCD_RS: LCD1.4, U1.11
MODE_SEL: R16.1, S2.3, S2.4 (P1), U1.19
unnamed: C5.+, J1.3, U5.IN
unnamed: C6.1, D2.C, R7.2
unnamed: C3.+, U2.P$19 (ZOUT1)
unnamed: C3.-, R1.1, R3.2
unnamed: D1.A, D2.A, R3.1, R4.2
unnamed: C2.1, CON1.CENTER, R1.2
unnamed: C2.2, D1.C, R2.2
unnamed: C1.1, R2.1, R12.2, U3.5 (IN+2)
unnamed: C7.1, R7.1, R8.2, U3.3 (IN+1)
unnamed: S1.3, S1.4 (P1), U1.22
unnamed: R9.1, R10.1, U3.6 (IN-2)
unnamed: R5.1, R6.2, U3.2 (IN-1)
unnamed: LCD1.15, R13.1
unnamed: LCD1.3, R14.1, R15.1, R18.2 (3)
TONE: P1.1, U1.9
V_FWD: R9.2, U1.17, U3.7 (OUT2)
V_REV: R5.2, U1.18, U3.1 (OUT1)

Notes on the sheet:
HamRadio 360
The Workbench Podcast
K6BEZ Antenna Analyzer
Page 1 of 1 December 2016
PCB Version 7

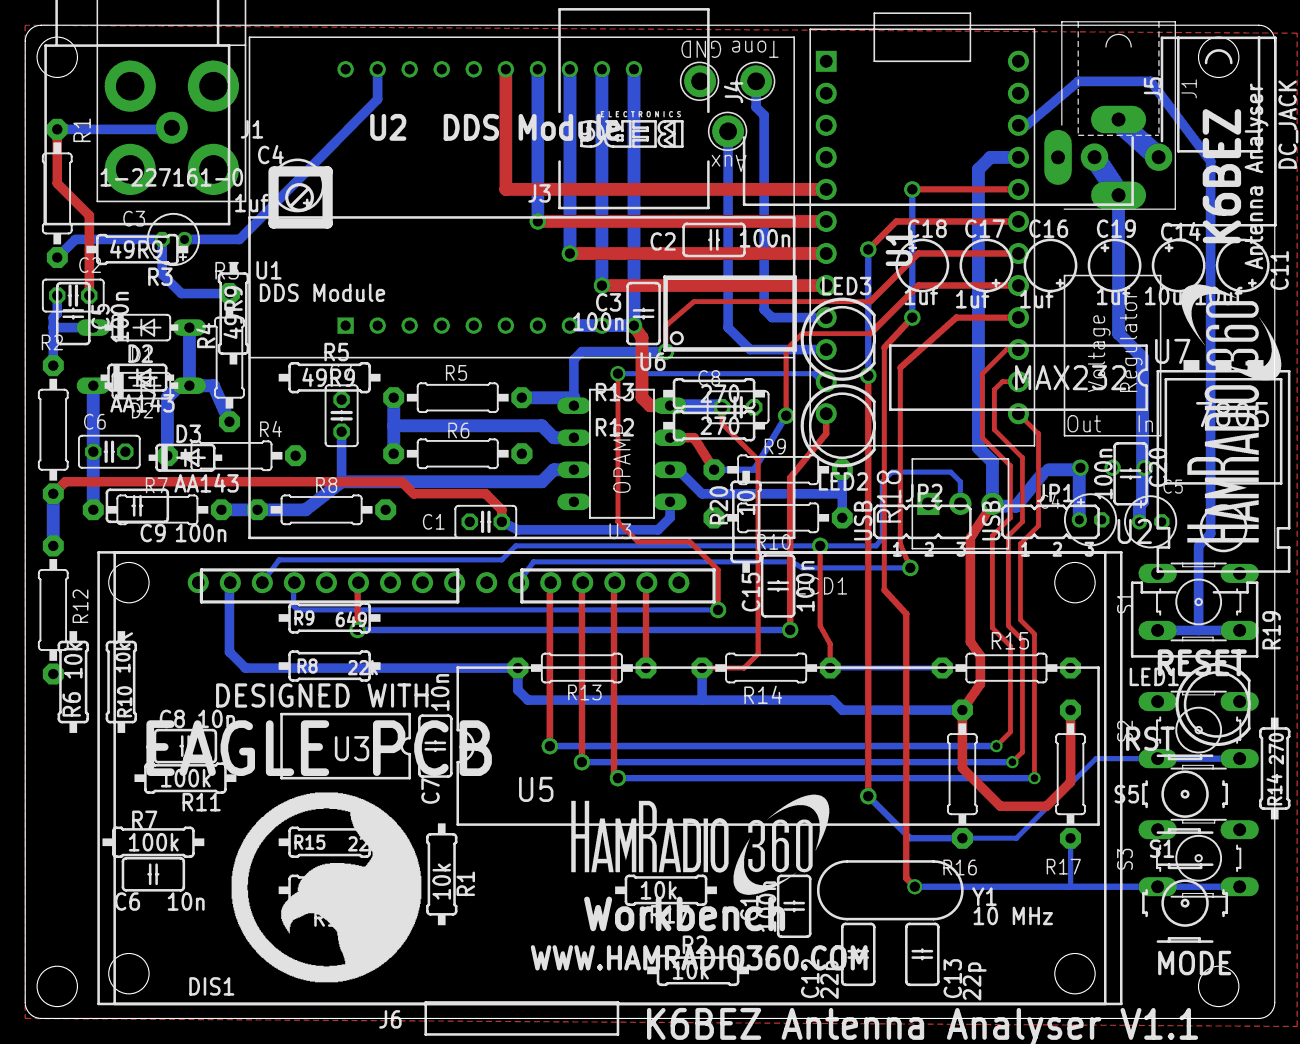
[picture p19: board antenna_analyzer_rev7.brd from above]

Board: 2 copper layers, 99.1 x 78.7 mm, 42 parts (1 on the bottom side), 32 nets.

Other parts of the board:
U$1, U$2: CS-2016-LOGO-15MM

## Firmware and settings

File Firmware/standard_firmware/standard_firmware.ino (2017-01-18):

// This file is part of the K6BEZ Antenna Analyzer project.
//
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
// include the library code:
#include <LiquidCrystal.h>

// * LCD RS pin to digital pin 8
// * LCD Enable pin to digital pin 9
// * LCD D4 pin to digital pin 15
// * LCD D5 pin to digital pin 14
// * LCD D6 pin to digital pin 16
// * LCD D7 pin to digital pin 10

// initialize the library with the numbers of the interface pins
LiquidCrystal lcd(8, 9, 15, 14, 16, 10);

#define FQ_UD 4
#define SDAT 3
#define SCLK 5
#define RESET 2
#define MODE A2
#define BAND A3


long Fstart = 1000000;  // Start Frequency for sweep
long Fstop = 30000000;  // Stop Frequency for sweep
unsigned long current_freq; // Temp variable used during sweep
long serial_input_number; // Used to build number from serial stream
long num_steps = 1001; // Number of steps to use in the sweep
char incoming_char; // Character read from serial stream
byte mode_pressed = 0;
int mode = 1;

void setup() {
  // set up the LCD's number of columns and rows:
  lcd.begin(16, 2);

  // Print a message to the LCD.
  lcd.print("Antenna Analyzer");

  // Configure DDS control pins for digital output
  pinMode(FQ_UD, OUTPUT);
  pinMode(SCLK, OUTPUT);
  pinMode(SDAT, OUTPUT);
  pinMode(RESET, OUTPUT);

  // Set up analog inputs on A0 and A1, internal reference voltage
  pinMode(A0, INPUT);
  pinMode(A1, INPUT);
  analogReference(DEFAULT);

  // initialize serial communication
  Serial.begin(115200);

  // Reset the DDS
  digitalWrite(RESET, HIGH);
  digitalWrite(RESET, LOW);

  //Initialise the incoming serial number to zero
  serial_input_number = 0;
  lcd.clear();
  lcd.setCursor(0, 0);
  lcd.print("1-30 MHz");
}

void loop() {
  //Check for character
  if (Serial.available() > 0) {
    mode = 0;
    lcd.clear();
    lcd.setCursor(14, 0);
    lcd.print("PC");
    incoming_char = Serial.read();
    switch (incoming_char) {
      case '0':
      case '1':
      case '2':
      case '3':
      case '4':
      case '5':
      case '6':
      case '7':
      case '8':
      case '9':
        serial_input_number = serial_input_number * 10 + (incoming_char - '0');
        break;
      case 'A':
        //Turn frequency into FStart
        Fstart = serial_input_number;
        serial_input_number = 0;
        break;
      case 'B':
        //Turn frequency into FStop
        Fstop = serial_input_number;
        serial_input_number = 0;
        break;
      case 'C':
        //Turn frequency into FStart and set DDS output to single frequency
        Fstart = serial_input_number;
        SetDDSFreq(Fstart);
        serial_input_number = 0;
        break;
      case 'N':
        // Set number of steps in the sweep
        num_steps = serial_input_number;
        serial_input_number = 0;
        break;
      case 'S':
      case 's':
        Perform_sweep();
        break;
      case '?':
        // Report current configuration to PC
        Serial.print("Start Freq:");
        Serial.println(Fstart);
        Serial.print("Stop Freq:");
        Serial.println(Fstop);
        Serial.print("Num Steps:");
        Serial.println(num_steps);
        break;
    }
    Serial.flush();
  } else {
    //No serial data was received
    if (mode > 0) {
      Perform_sweep();
    }
  }

  if ((digitalRead(BAND) == LOW) or (mode_pressed == 1)) {
    mode_pressed = 0;
    mode += 1;
    if (mode == 12) {
      mode = 1;
    }
    num_steps = 1000;

    switch(mode){
      case 1:
        // Full sweep 1-30 MHz
        lcd.clear();
        lcd.setCursor(0, 0);
        lcd.print("1-30 MHz");
        Fstart = 1000000;
        Fstop = 30000000;
        break;
      case 2:
        // 160m
        lcd.clear();
        lcd.setCursor(0, 0);
        lcd.print("160m");
        Fstart = 1500000;
        Fstop = 2300000;
        break;
      case 3:
        // 80m
        lcd.clear();
        lcd.setCursor(0, 0);
        lcd.print("80m");
        Fstart = 2000000;
        Fstop = 5000000;
        break;
      case 4:
        // 60m
        lcd.clear();
        lcd.setCursor(0, 0);
        lcd.print("60m");
        Fstart = 5000000;
        Fstop = 6000000;
        break;
      case 5:
        // 40m
        lcd.clear();
        lcd.setCursor(0, 0);
        lcd.print("40m");
        Fstart = 6000000;
        Fstop = 8000000;
        break;
      case 6:
        // 30m
        lcd.clear();
        lcd.setCursor(0, 0);
        lcd.print("30m");
        Fstart = 9000000;
        Fstop = 11000000;
        break;
      case 7:
        // 20m
        lcd.clear();
        lcd.setCursor(0, 0);
        lcd.print("20m");
        Fstart = 13000000;
        Fstop = 16000000;
        break;
      case 8:
        // 17m
        lcd.clear();
        lcd.setCursor(0, 0);
        lcd.print("17m");
        Fstart = 17000000;
        Fstop = 19000000;
        break;
      case 9:
        // 15m
        lcd.clear();
        lcd.setCursor(0, 0);
        lcd.print("15m");
        Fstart = 20000000;
        Fstop = 23000000;
        break;
      case 10:
        // 12m
        lcd.clear();
        lcd.setCursor(0, 0);
        lcd.print("12m");
        Fstart = 24000000;
        Fstop = 26000000;
        break;
      case 11:
        // 10m
        lcd.clear();
        lcd.setCursor(0, 0);
        lcd.print("10m");
        Fstart = 28000000;
        Fstop = 30000000;
        break;

    }
  }
}

void Perform_sweep() {
  int FWD = 0;
  int REV = 0;
  int REV_nosig = 0;
  int FWD_nosig = 0;
  double VSWR;
  double minVSWR;
  long minFreq;
  long Fstep = (Fstop - Fstart) / num_steps;
  minVSWR = 999;
  minFreq = Fstart;

  // Reset the DDS
  digitalWrite(RESET, HIGH);
  delay(1);
  digitalWrite(RESET, LOW);
  delay(10);
  SetDDSFreq(Fstart);
  delay(100);

//  REV_nosig = analogRead(A0);
//  FWD_nosig = analogRead(A1);
//  if(mode==0){
//    Serial.print("FWD ");
//    Serial.print(FWD_nosig);
//    Serial.print(", REV ");
//    Serial.println(REV_nosig);
//    Serial.flush();
//  }



  // Start loop
  for (long i = 0; i <= num_steps; i++) {
    // Calculate current frequency
    current_freq = Fstart + i * Fstep;

    // Set DDS to current frequency
    SetDDSFreq(current_freq);
    // Wait a little for settling
    if (digitalRead(BAND) == LOW) {
      mode_pressed = 1;
    }
    delay(10);
    // Read the forawrd and reverse voltages
    REV = analogRead(A0);
    FWD = analogRead(A1);

    if (REV >= FWD) {
      // To avoid a divide by zero or negative VSWR then set to max 999
      VSWR = 999;
    } else {
      // Calculate VSWR
      VSWR = ((double)FWD + (double)REV) / ((double)FWD - (double)REV);
    }

    if (VSWR <= minVSWR) {
      minFreq = current_freq;
      minVSWR = VSWR;
    }

    if (mode == 0) {
      // Send current line back to PC over serial bus
      Serial.print(current_freq);
      Serial.print(",");
      Serial.print(long(VSWR * 1000)); // This *1000 is to make the system compatible with the PIC version
      Serial.print(",");
      Serial.print(FWD);
      Serial.print(",");
      Serial.println(REV);
    }
  }

  // Send "End" to PC to indicate end of sweep
  if (mode == 0) {
    Serial.println("End");
    Serial.print("Freq ");
    Serial.print(minFreq);
    Serial.print(", VSWR ");
    Serial.println(minVSWR);
    Serial.flush();
  }

  lcd.setCursor(15, 1);
  lcd.print(".");
  delay(100);
  lcd.setCursor(15, 1);
  lcd.print(" ");
  lcd.setCursor(0, 1);
  lcd.print(minFreq);
  lcd.print(",");
  lcd.print(minVSWR);
  lcd.print(":1    ");

  digitalWrite(13, HIGH);
  //delay(10);
  digitalWrite(13, LOW);
}

void SetDDSFreq(long Freq_Hz) {
  // Calculate the DDS word - from AD9850 Datasheet
  int32_t f = Freq_Hz * 4294967295 / 125000000;

  // Send one byte at a time
  for (int b = 0; b < 4; b++, f >>= 8) {
//    SPI.transfer(f & 0xFF);
    send_byte(f & 0xFF);
  }

  // 5th byte needs to be zeros
  //SPI.transfer(0);
  send_byte(0);

  // Strobe the Update pin to tell DDS to use values
  digitalWrite(FQ_UD, HIGH);
  digitalWrite(FQ_UD, LOW);
}

void send_byte(byte data_to_send) {
  // Bit bang the byte over the SPI bus
  for (int i = 0; i < 8; i++, data_to_send >>= 1) {
    // Set Data bit on output pin
    digitalWrite(SDAT, data_to_send & 0x01);
    // Strobe the clock pin
    digitalWrite(SCLK, HIGH);
    digitalWrite(SCLK, LOW);
  }
}

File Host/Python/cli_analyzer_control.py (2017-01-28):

# HamRadio360_SWR_analyzer_control_KB5EZ.py
# Sample HR360 build project SWR analyzer interface 

# by Rob Suggs/KB5EZ 18 Jan 2017, modified 23 Jan 2017
# open source and free to use as you wish

# info on Serial package at http://pyserial.readthedocs.io/en/latest/examples.html 
# pyserial 2.7 download at https://pypi.python.org/pypi/pyserial/2.7 
# installation instructions http://pyserial.readthedocs.io/en/latest/pyserial.html#installation
# other packages bundled with Python(X,Y) distribution

import serial # serial interface package
import numpy as np # numerical analysis package
import matplotlib.pyplot as plt # plotting package

ser = serial.Serial('/dev/ttyACM0', baudrate = 115200)
# ser port (my COM10) is the Arduino virtual serial port
# change port to /dev/ttyACM0 for Linux
# baud rate is set in the Arduino sketch

band = 20 # pick the band of interest

comment = 'mMA5B_HR360_analyzer' # this will be in figure title and file name

num_steps = 100 # number of samples across the band, 1 more for upper band edge

# band edges
# HR360 Analyzer expects the numbers in Hz
start = {10:28000000,12:24890000,15:21001000,17:18068000,20:14000000,
         30:10100000,40:7000000,80:3500000,160:1800000}
         
end   = {10:29700000,12:24990000,15:21450000,17:18168000,20:14350000,
         30:10150000,40:7300000,80:4000000,160:2000000}     

# build the commands for the SWR analyzer

start_freq = "%08d" % start[band] + "A"
end_freq   = "%08d" % end[band]   + "B"
steps      = "%04d" % num_steps   + "N"

# for single freq - not implemented
#freq    = "%08d" % freq_single + "C"

print 'Commands ', start_freq, end_freq, steps

ser.write(start_freq) # set start frequency
ser.write(end_freq)   # set end freq
ser.write(steps)      # set number of steps
ser.write("S")        # start sweep

for i in range(num_steps): # setup loop over number of points
    in_string = ser.readline() # read a line from the Arduino
#    print 'index =',i, "string = ",in_string # check the read

# parse the input string to obtain freq and swr, convert to MHz and swr
# these values could be loaded in arrays for fancy plot and analysis
    freq_swr_string = in_string.split(",") # break the comma-separated input string
    freq_cur = np.float(freq_swr_string[0])/1.e6
    vswr     = np.float(freq_swr_string[1])/1.e3 # voltage readings are 2 and 3
    print "Freq = ", freq_cur, "  VSWR = ",vswr

# Plot the SWR
    plt.plot(freq_cur,vswr,'ro') # plot the SWR as a red dot (r o)

# you could read the min SWR and freq or compute them in Python

ser = serial.Serial.close # close the  port

# finish the plot and save it
plt.title('SWR '+str(band)+'m band '+comment) # concatenate some strings for title
plt.xlabel('Freq MHz') # X axis label
plt.ylabel('SWR')      # Y axis label
plt.ylim(1.,5.)        # set the Y axis limits from SWR = 1 to 5
plt.savefig(str(band)+comment+'.png',format='png') # build a filename and save the figure
plt.show()  # display the figure in the console
# end of program
#==============================================================================

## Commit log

2016-12-07 Added Antenna Analyzer schematic rev 7
2016-12-07 Moved schematic to Hardware
    Created a hardware folder for better organization
2017-01-12 Added rev 7 pcb files and documentation
    [antenna_analyzer_bom.xlsx, antenna_analyzer_rev7.brd, antenna_analyzer_rev7.sch]

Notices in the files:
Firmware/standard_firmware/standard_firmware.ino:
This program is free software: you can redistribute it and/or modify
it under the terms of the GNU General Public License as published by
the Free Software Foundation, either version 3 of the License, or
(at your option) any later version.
